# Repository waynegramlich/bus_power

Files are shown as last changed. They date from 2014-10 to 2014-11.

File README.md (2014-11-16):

# bus_power

This printed circuit board provides the ability to connect
up to two separate batteries to the bus -- one for powering
logic and the other for powering motors.  The board has
polarity protection circuitry to deal with accidentally
connecting the power up backwards.  In addition there are
polyfuses (which are kind of like circuit breakers) that protect
against accidental shorts.

## MOSFET Polarity Protection Video

There is a nifty
[YouTube video](https://www.youtube.com/watch?v=IrB-FPcv1Dc)
that explains how a P-channel MOSFET polarity protection circuit
works.

## Revision A

The revision A schematic can be found in the `rev_a` directory
in either `bus_power.pdf` or `bus_power.svg`.  Some relevant
data sheets can be found in the `docs` folder.

The motor (i.e. battery) power can be connected to either N4 or N5
which can be used daisy chain to other power connecors.  N3 is
an Emergency Stop connector.  If you do not have an emergency
stop button this connector must have a wire that shorts between
pins 1 and 2.  The positive power is run through a P-channel
MOSFET (Q1) for polarity protection.  A MOSFET has a much lower
voltage loss than silicon diodes or Schottky diodes.  The power
then goes through a 3 Ampere polyfuse (R2).  If 3 Amperes
is exceeded, the polyfuse will warm up and go into a high resistance
state.  Finally, the power goes through SW1, which is a double
pole, single through switch to the bus connector N2.

The logic power goes through two daisy chain connectors (N6, N7),
a P-channel polarity protection MOSFET (Q2), a 3 Ampere polyfuse
(R3) and the switch (SW1) before providing logic power to the
bus connector (N2).

If this board is at the end of the bus, the termination jumper
(J1) can be connected between pins 1 and 2 to provide 120 Ohms
of bus termination via R1.

## Revision A Issues

* Power switch does not control daisy chain power.

* The bus connector should be centered.

* Provide a power on/off LED.

## Revision B Issues

* There is request for a jumperable power LED.

* Are terminal blocks oriented backwards?

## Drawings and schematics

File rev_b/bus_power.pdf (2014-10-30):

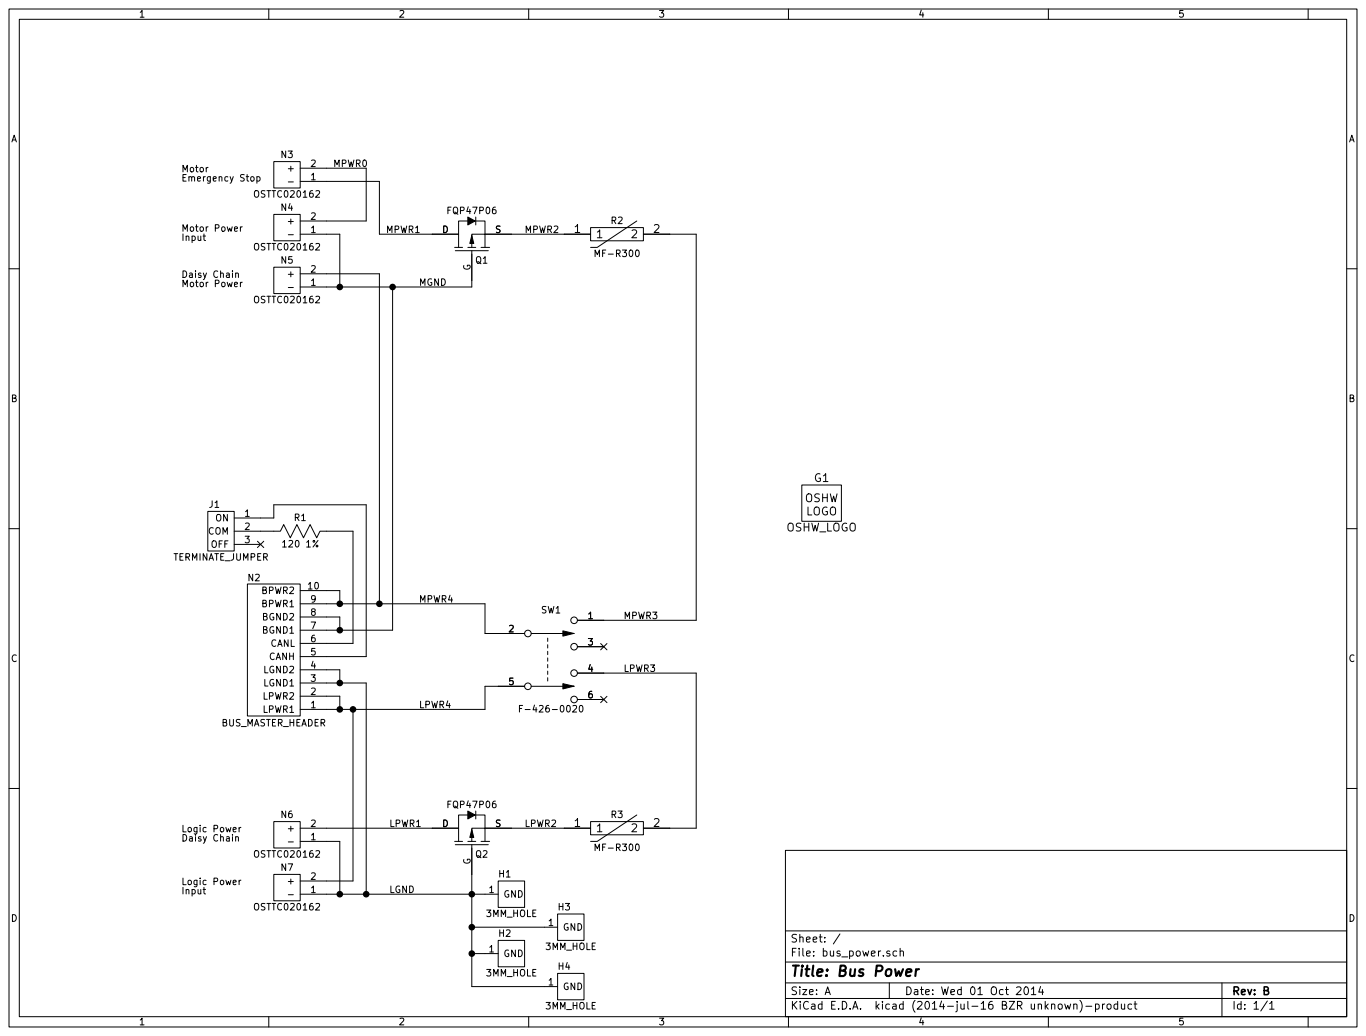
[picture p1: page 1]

Daisy Chain Motor Power Motor Emergency Stop
Input

File: bus_power.sch Sheet: / GND 1 H1

Id: 1/1 Title: Bus Power

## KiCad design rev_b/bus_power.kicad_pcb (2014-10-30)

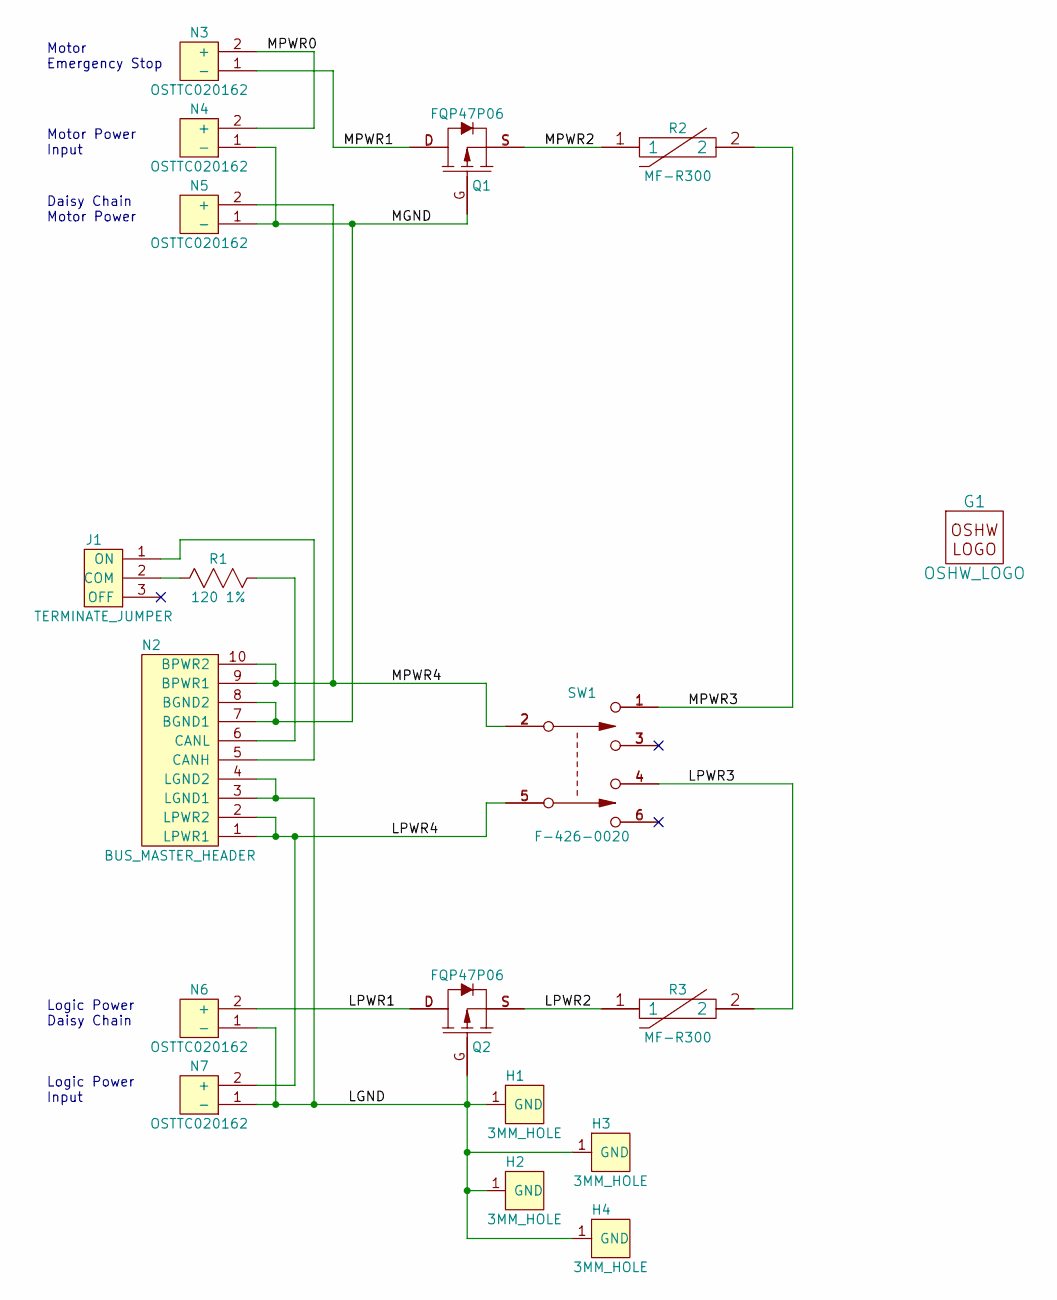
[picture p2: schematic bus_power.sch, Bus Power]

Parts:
G1: OSHW_LOGO
H1, H2, H3, H4: 3MM_HOLE
J1: TERMINATE_JUMPER
N2: BUS_MASTER_HEADER
N3, N4, N5, N6, N7: OSTTC020162
Q1, Q2: FQP47P06
R1: 120 1%
R2, R3: MF-R300
SW1: F-426-0020

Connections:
/LGND: H1.1, H2.1, H3.1, H4.1, N2.3 (LGND1), N2.4 (LGND2), N6.1 (-), N7.1 (-), Q2.G
/LPWR1: N6.2 (+), Q2.D
/LPWR2: Q2.S, R3.1
/LPWR3: R3.2, SW1.4
/LPWR4: N2.1 (LPWR1), N2.2 (LPWR2), N7.2 (+), SW1.5
/MGND: N2.7 (BGND1), N2.8 (BGND2), N4.1 (-), N5.1 (-), Q1.G
/MPWR0: N3.2 (+), N4.2 (+)
/MPWR1: N3.1 (-), Q1.D
/MPWR2: Q1.S, R2.1
/MPWR3: R2.2, SW1.1
/MPWR4: N2.9 (BPWR1), N2.10 (BPWR2), N5.2 (+), SW1.2
unnamed: J1.1 (ON), N2.5 (CANH)
unnamed: J1.2 (COM), R1.1
unnamed: N2.6 (CANL), R1.2

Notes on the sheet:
Daisy Chain Motor Power
Motor Emergency Stop
Logic Power Input
Motor Power Input
Logic Power Daisy Chain

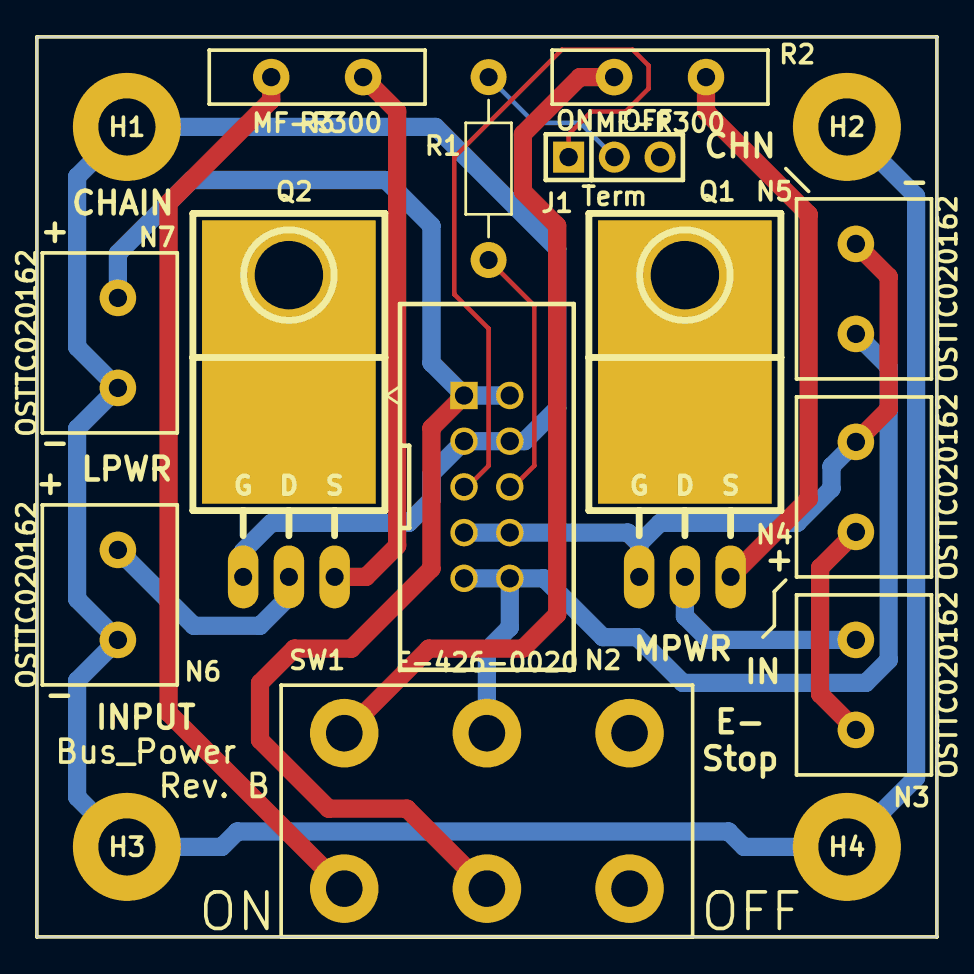
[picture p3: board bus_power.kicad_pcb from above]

Board: 2 copper layers, 50.0 x 50.0 mm, 18 parts (1 on the bottom side), 14 nets.

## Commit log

2014-08-11 Initial clone of mini_power.
    [bus_power.kicad_pcb, bus_power.sch]
2014-08-11 Finnished Revision A layout.
    [bus_power-B_Cu.gbl, bus_power-B_Mask.gbs, bus_power-B_SilkS.gbo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]
2014-08-18 Added silkscreen outline.
    [bus_power-B_Cu.gbl, bus_power-B_Mask.gbs, bus_power-B_SilkS.gbo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]
2014-10-02 Cloned Rev. B. from Rev. A
    [bus_power-B_Cu.gbl, bus_power-B_Mask.gbs, bus_power-B_SilkS.gbo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]
2014-10-02 Did first layout of Rev. B.
    [$bus_power.sch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]
2014-10-02 Forgot to update schematic.
    [$bus_power.sch, bus_power.sch]
2014-10-30 Wrapped up Rev. B
    [bus_power-B_Cu.gbl, bus_power-B_Mask.gbs, bus_power-B_SilkS.gbo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]
